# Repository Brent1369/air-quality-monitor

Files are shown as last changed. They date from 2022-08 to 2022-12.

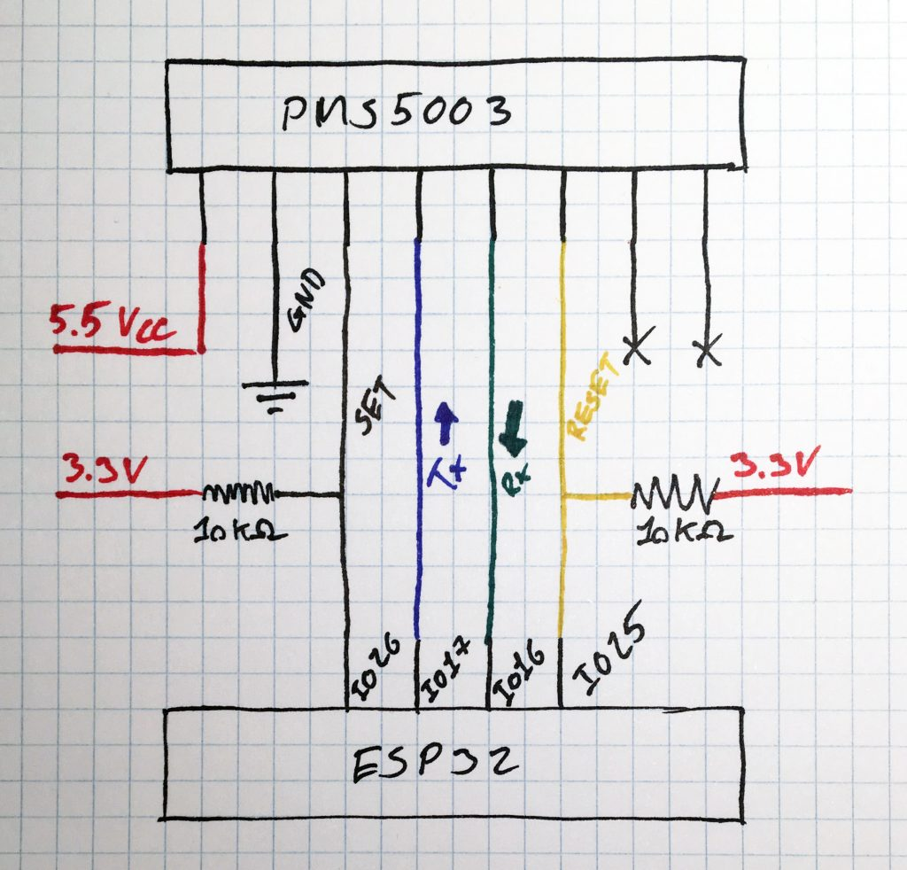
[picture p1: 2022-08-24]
PMS5003 wiring.png

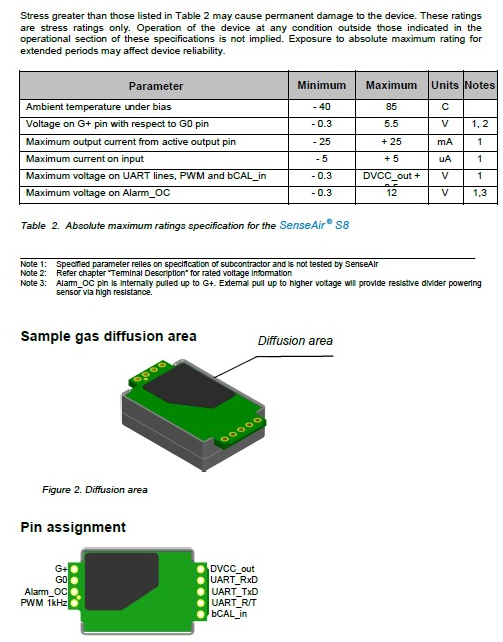
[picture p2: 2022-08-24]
CO2 sensor.png

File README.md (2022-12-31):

hoevele uren?
10 uur opzoeken welke componenten ik ging gebruiken en hoe het design er ging uit zien

3 uur door verkeerde pinnen esp32 (hardware serial)

3 uur aan CO2 sensor testen
met softwareserial leren werke
3 uur omdat verkeerde pinnen

met lcd werken er weer esp32 pinnen niet

co2 aan rx tx
5 uur omdat stofsensor aan boot van arduino hange en dus de hele tijd bootte

3 uur geen beeld op lcd aand input only

5 uur aan tft display gewerkt om alles fatsoenlijk te maken

3 uur mq sensors
weerstand verandert

3 uur temperature sensor verkeerde waardes
2 uur andere temp sensor getest

altium begin
geleerd arduino pinnen bekijken

5 uur pcb

7-9 design case

10 uur assembly case, brass inserts vol plastiek moeten kuisen

7-10 uur lcd solder

5 uur nieuw design
nieuw case design vergeten schrtoef schuine dingen

3 uur calibreren en testen

1 uur knop kapot

3 uur readme

Deze Air quality monitor meet CO2, stofdeeltjes in de lucht, CO, VOC, temperatuur en vochtigheid

https://user-images.githubusercontent.com/69217508/194945470-0f83bcbc-d27d-4c34-872a-e3b75baa7aa3.MOV

CO2 waardes buiten zijn ongeveer 400-500 ppm  
CO2 waardes slaapkamer test:  
raam dicht  

raam open


Breadboard testing


PCB TOP

PCB BOT


case top


case top upside down

case bottom


case botton upside down


pcb with component


hot insert


pcb assembly


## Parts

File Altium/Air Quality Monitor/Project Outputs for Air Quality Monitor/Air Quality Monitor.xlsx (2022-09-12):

Comment | Description | Designator | Footprint | LibRef | Quantity
buzzer |  | BUZ | buzzer | buzzer | 1
USB4085-GF-A | CONN RCPT USB2.0 TYPE C 24POS RA | J1 | FP-USB4085-GF-A-MFG | CMP-196119-000001-2 | 1
61300811121 | THT Vertical Pin Header WR-PHD, Pitch 2.54 mm, Single Row, 8 pins | LCD | 61300811121 | CMP-1502-01076-1 | 1
POLOLU-1482 | Integrated Circuit | MQ7, MQ135 | POLOLU1482 | POLOLU-1482 | 2
pms5003 |  | pms5003 | pms5003 | pms5003 | 1
2N7000 | Small Signal MOSFET, 200 mA, 60 V, N-Channel, 3-Pin TO-92, Bulk Box | Q1 | ONSC-TO-92-3-29-11 | CMP-1058-00936-1 | 1
10k | RES SMD 0 OHM JUMPER 1/4W 1206 | R1, R2 | FP-RC1206-MFG | CMP-2100-03681-2 | 2
1M | RES SMD 0 OHM JUMPER 1/4W 1206 | R3 | FP-RC1206-MFG | CMP-2100-03681-2 | 1
2k | RES SMD 0 OHM JUMPER 1/4W 1206 | R4, R5 | FP-RC1206-MFG | CMP-2100-03681-2 | 2
SS12D00G3 | Switch | S1 | SS12D00G3 | SS12D00G3 | 1
006-0-0002 | Carbon Dioxide (CO2) Sensor | SenseAir S8 | XDCR_006-0-0002 | 006-0-0002 | 1
61300411121 | THT Vertical Pin Header WR-PHD, Pitch 2.54 mm, Single Row, 4 pins | SHT31 | 61300411121 | CMP-1502-01064-1 | 1
3-1825910-1 | SWITCH TACTILE SPST-NO 0.05A 24V | SW1 | FP-3-1825910-1-MFG | CMP-03407-000001-1 | 1
ESP32-DEVKITC-32D | Eval Board For Esp-Wroom-32 | U1 | MODULE_ESP32-DEVKITC-32D | ESP32-DEVKITC-32D | 1

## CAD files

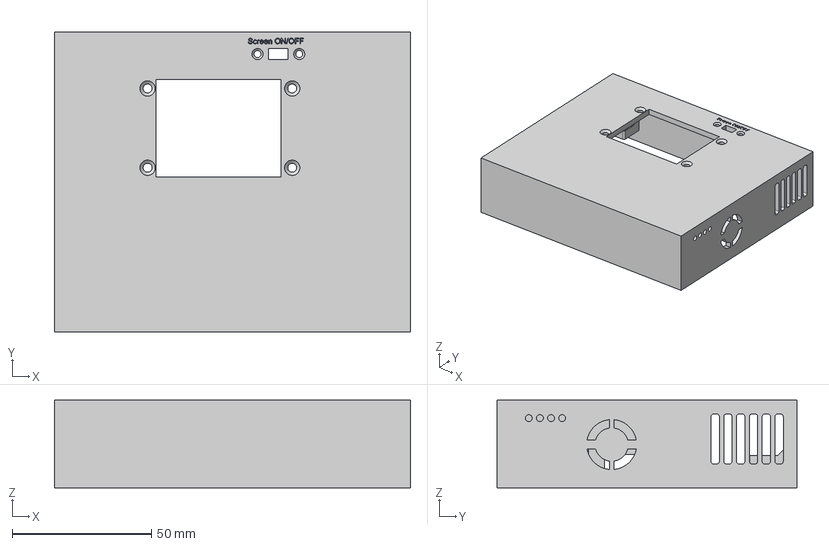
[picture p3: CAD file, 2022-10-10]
Altium/Air Quality Monitor/top.step
128.0 x 108.0 x 31.6 mm

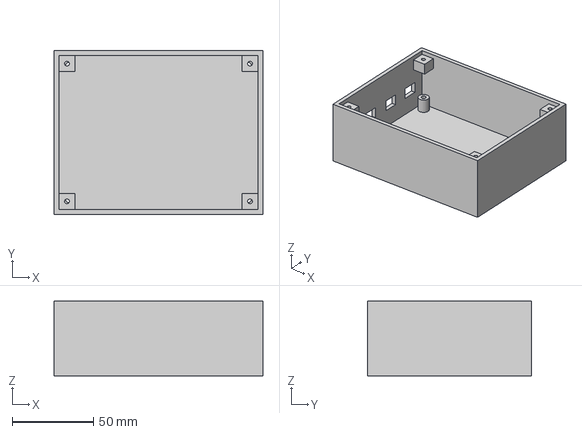
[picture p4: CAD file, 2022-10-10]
Altium/Air Quality Monitor/Body1.3mf
129.0 x 101.0 x 46.0 mm

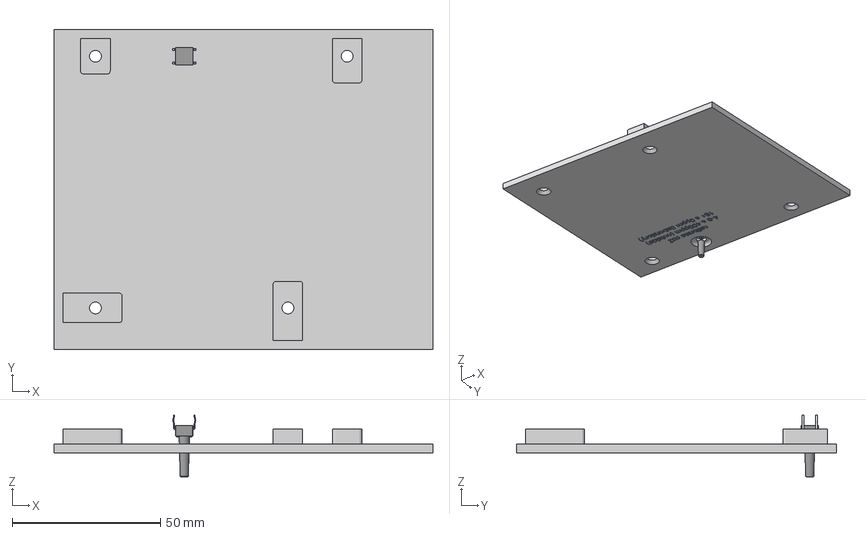
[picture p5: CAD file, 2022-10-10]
Altium/Air Quality Monitor/Air quality monitor v19.3mf
128.0 x 108.0 x 20.8 mm

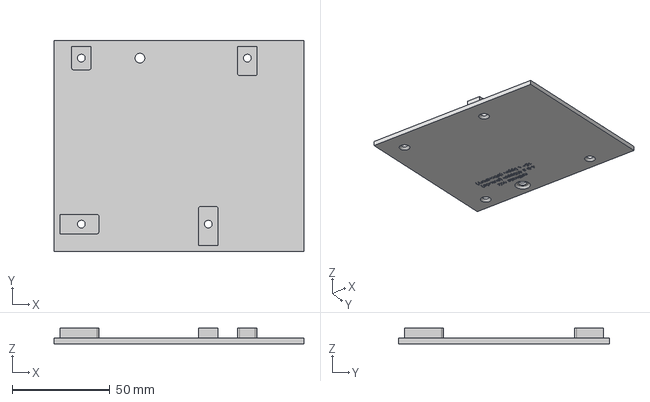
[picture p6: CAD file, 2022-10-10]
Altium/Air Quality Monitor/Component51.step
128.0 x 108.0 x 8.00 mm

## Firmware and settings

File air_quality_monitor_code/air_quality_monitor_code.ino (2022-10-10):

#include <Arduino.h>
#include "s8_uart.h"
#include <SoftwareSerial.h>
#include <Adafruit_GFX.h>    // Core graphics library
#include <Adafruit_ST7735.h> // Hardware-specific library for ST7735
#include <Adafruit_ST7789.h> // Hardware-specific library for ST7789
#include <SPI.h>
#include <Wire.h>
#include "Adafruit_SHT31.h"
#include <MQUnifiedsensor.h>

#define DEBUG_BAUDRATE 9600

#define VOLTAGE 3.3

#define TFT_CS 32
#define TFT_DC  26
#define TFT_RST 27

#define TFT_MOSI 25  // Data out
#define TFT_SCLK 33  // Clock out

#define pms5003_RX_PIN 19       // Rx pin which the S8 Tx pin is attached to (change if it is needed)
#define pms5003_TX_PIN 18         // Tx pin which the S8 Rx pin is attached to (change if it is needed)


#define S8_RX_PIN 17        // Rx pin which the S8 Tx pin is attached to (change if it is needed)
#define S8_TX_PIN 23         // Tx pin which the S8 Rx pin is attached to (change if it is needed)

SoftwareSerial S8_serial(S8_RX_PIN, S8_TX_PIN);
S8_UART *sensor_S8;
S8_sensor sensor;


SoftwareSerial  pmsSerial( pms5003_RX_PIN, pms5003_TX_PIN);

struct pms5003data {
  uint16_t framelen;
  uint16_t pm10_standard, pm25_standard, pm100_standard;
  uint16_t pm10_env, pm25_env, pm100_env;
  uint16_t particles_03um, particles_05um, particles_10um, particles_25um, particles_50um, particles_100um;
  uint16_t unused;
  uint16_t checksum;
};

struct pms5003data data;

float p = 3.1415926;
Adafruit_ST7735 tft = Adafruit_ST7735(TFT_CS, TFT_DC, TFT_MOSI, TFT_SCLK, TFT_RST);

//boolean readPMSdata(Stream *s); 
//void TextLCD(char *text, uint16_t color, uint16_t x, uint16_t y);

bool enableHeater = false;
uint8_t loopCnt = 0;

Adafruit_SHT31 sht31 = Adafruit_SHT31();

void setup() {
   tft.initR(INITR_BLACKTAB);      // Init ST7735S chip, black tab
  // Configure serial port, we need it for debug
  Serial.begin(9600);

  // Wait port is open or timeout
  int i = 0;
  while (!Serial && i < 50) {
    delay(10);
    i++;
  }
  // First message, we are alive
  Serial.println("");
  Serial.println("Init");

  // Initialize S8 sensor
  S8_serial.begin(S8_BAUDRATE);
  sensor_S8 = new S8_UART(S8_serial);

  //pms5003_serial.begin(S8_BAUDRATE);
pmsSerial.begin(9600);


  // Check if S8 is available
  sensor_S8->get_firmware_version(sensor.firm_version);
  int len = strlen(sensor.firm_version);
  if (len == 0) {
      Serial.println("SenseAir S8 CO2 sensor not found!");
      while (1) { delay(1); };
  }

  // Show basic S8 sensor info
  Serial.println(">>> SenseAir S8 NDIR CO2 sensor <<<");
  printf("Firmware version: %s\n", sensor.firm_version);
  sensor.sensor_id = sensor_S8->get_sensor_ID();
  Serial.print("Sensor ID: 0x"); printIntToHex(sensor.sensor_id, 4); Serial.println("");

  Serial.println("Setup done!");
  Serial.flush();


    Serial.println(F("Initialized"));

  uint16_t time = millis();
  tft.fillScreen(ST77XX_BLACK);
  time = millis() - time;

  Serial.println(time, DEC);
  delay(500);

  // large block of text
  tft.fillScreen(ST77XX_BLACK);
   tft.setRotation(3);
   tft.setTextSize(1);
   //mq7.calibrate();    // calculates R0

sht31.begin(0x44);
  Serial.print("Heater Enabled State: ");
  if (sht31.isHeaterEnabled())
    Serial.println("ENABLED");
  else
    Serial.println("DISABLED");

/*
Serial.println("Starting manual calibration...");
  if (!sensor_S8->manual_calibration()) {
    Serial.println("Error setting manual calibration!");
    while (1) { delay(10); }
  }*/
    
}


void loop() {
  

  char buf [100]; 
  //printf("Millis: %lu\n", millis());

  // Get CO2 measure
  sensor.co2 = sensor_S8->get_co2();
 // printf("CO2 value: %d ppm\n", sensor.co2);
  memset(buf, ' ', 100);
  sprintf (buf, "CO2: %d ppm", sensor.co2);
  buf[strlen(buf)]=' ';
  Serial.println(buf);
  //tft.fillScreen(ST77XX_BLACK);
  TextLCD(buf, ST77XX_WHITE, 0, 10);
  //Serial.printf("/*%u*/\n", sensor.co2);   // Format to use with Serial Studio program

  // Compare with PWM output
  //sensor.pwm_output = sensor_S8->get_PWM_output();
  //printf("PWM output = %0.0f ppm\n", (sensor.pwm_output / 16383.0) * 2000.0);

  // Wait 5 second for next measure
  
  if (readPMSdata(&pmsSerial)) {
    // reading data was successful!
   // Serial.println();
   // Serial.println("---------------------------------------");
   // Serial.println("Concentration Units (standard)");
   // Serial.print("PM 1.0: "); Serial.print(data.pm10_standard);

    memset(buf, ' ', 100);
    sprintf (buf, "PM1.0: %d ug/m3", data.pm10_standard);
    buf[strlen(buf)]=' ';
    TextLCD(buf, ST77XX_WHITE, 0, 25);
      Serial.println(buf);
    //Serial.print("\t\tPM 2.5: "); Serial.print(data.pm25_standard);

    memset(buf, ' ', 100);
    sprintf (buf, "PM2.5: %d ug/m3", data.pm25_standard);
    buf[strlen(buf)]=' ';
    TextLCD(buf, ST77XX_WHITE, 0, 40);
    
    //Serial.print("\t\tPM10: "); Serial.println(data.pm100_standard);

    memset(buf, ' ', 100);
    sprintf (buf, "PM10 : %d ug/m3", data.pm100_standard);
    buf[strlen(buf)]=' ';
    TextLCD(buf, ST77XX_WHITE, 0, 55);
    
    /*Serial.println("---------------------------------------");
    Serial.println("Concentration Units (environmental)");
    Serial.print("PM 1.0: "); Serial.print(data.pm10_env);
    Serial.print("\t\tPM 2.5: "); Serial.print(data.pm25_env);
    Serial.print("\t\tPM 10: "); Serial.println(data.pm100_env);
    Serial.println("---------------------------------------");
    Serial.print("Particles > 0.3um / 0.1L air:"); Serial.println(data.particles_03um);
    Serial.print("Particles > 0.5um / 0.1L air:"); Serial.println(data.particles_05um);
    Serial.print("Particles > 1.0um / 0.1L air:"); Serial.println(data.particles_10um);
    Serial.print("Particles > 2.5um / 0.1L air:"); Serial.println(data.particles_25um);
    Serial.print("Particles > 5.0um / 0.1L air:"); Serial.println(data.particles_50um);
    Serial.print("Particles > 10.0 um / 0.1L air:"); Serial.println(data.particles_100um);
    Serial.println("---------------------------------------");*/
  }


  

  
   //Serial.print("PPM = "); Serial.println(mq7.readPpm());

   memset(buf, ' ', 100);
   float MQ7Percentage = ((float)analogRead(36)/4096)*100;
   sprintf (buf, "MQ7: %.2f %% CO", MQ7Percentage);
   buf[strlen(buf)]=' ';
   TextLCD(buf, ST77XX_WHITE, 0, 70);


 

  float MQ135Percentage = ((float)analogRead(39)/4096)*100;
  memset(buf, ' ', 100);
   sprintf (buf, "MQ135: %.2f  %% TVOC", MQ135Percentage);
   buf[strlen(buf)]=' ';
   TextLCD(buf, ST77XX_WHITE, 0, 85);



float t = sht31.readTemperature();
  float h = sht31.readHumidity();

  if (! isnan(t)) {  // check if 'is not a number'
    //Serial.print("Temp *C = "); Serial.print(t); Serial.print("\t\t");
     memset(buf, ' ', 100);
   sprintf (buf, "Temp: %.2f C ", t);
   buf[strlen(buf)]=' ';
   TextLCD(buf, ST77XX_WHITE, 0, 100);
  } else { 
    Serial.println("Failed to read temperature");
  }
  
  if (! isnan(h)) {  // check if 'is not a number'
    //Serial.print("Hum. % = "); Serial.println(h);
      memset(buf, ' ', 100);
   sprintf (buf, "Humidity: %.2f  %% ", h);
   buf[strlen(buf)]=' ';
   TextLCD(buf, ST77XX_WHITE, 0, 115);
  } else { 
    Serial.println("Failed to read humidity");
  }

  delay(100);

  // Toggle heater enabled state every 30 seconds
  // An ~3.0 degC temperature increase can be noted when heater is enabled
  /*
  if (loopCnt >= 30) {
    enableHeater = !enableHeater;
    sht31.heater(enableHeater);
    Serial.print("Heater Enabled State: ");
    if (sht31.isHeaterEnabled())
      Serial.println("ENABLED");
    else
      Serial.println("DISABLED");

    loopCnt = 0;
  }
  loopCnt++;
*/


  
}


void TextLCD(char *text, uint16_t color, uint16_t x, uint16_t y)  {
  tft.setCursor(x, y);
  tft.setTextColor(color, ST77XX_BLACK);
  tft.setTextWrap(false);
  tft.print(text);

}

boolean readPMSdata(Stream *s) {
  if (! s->available()) {
    return false;
  }
  
  // Read a byte at a time until we get to the special '0x42' start-byte
  if (s->peek() != 0x42) {
    s->read();
    return false;
  }
 
  // Now read all 32 bytes
  if (s->available() < 32) {
    return false;
  }
    
  uint8_t buffer[32];    
  uint16_t sum = 0;
  s->readBytes(buffer, 32);
 
  // get checksum ready
  for (uint8_t i=0; i<30; i++) {
    sum += buffer[i];
  }
 
  /* debugging
  for (uint8_t i=2; i<32; i++) {
    Serial.print("0x"); Serial.print(buffer[i], HEX); Serial.print(", ");
  }
  Serial.println();
  */
  
  // The data comes in endian'd, this solves it so it works on all platforms
  uint16_t buffer_u16[15];
  for (uint8_t i=0; i<15; i++) {
    buffer_u16[i] = buffer[2 + i*2 + 1];
    buffer_u16[i] += (buffer[2 + i*2] << 8);
  }
 
  // put it into a nice struct :)
  memcpy((void *)&data, (void *)buffer_u16, 30);
 
  if (sum != data.checksum) {
    Serial.println("Checksum failure");
    return false;
  }
  // success!
  return true;
}

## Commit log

2022-08-24 co2 sensor works
2022-08-24 code dust sensor works
2022-08-25 mq sensors work
    [Air Quality Monitor.PrjPcb, Sheet1.SchDoc]
2022-08-25 temperature sensor works a little bit
2022-08-26 started altium
    [Air Quality Monitor.PrjPcb, PCB1.PcbDoc, PcbLib1.PcbLib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]
2022-08-26 electrical schematic almost done
    [PCB1.PcbDoc, PcbLib1.PcbLib, Schlib1.SchLib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]
2022-08-27 pcb almost done
    [PCB1.PcbDoc, PcbLib1.PcbLib, Schlib1.SchLib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]
2022-08-27 electrical schematic finished
    [Air Quality Monitor.PrjPcb, PCB1.PcbDoc, Sheet1.SchDoc]
2022-08-27 pcb finished
    [Air Quality Monitor.PrjPcb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]
2022-09-10 created and almost finished case design
2022-10-10 case finish
    [Air quality monitor v19.3mf, Body1.3mf, Component51.step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]
